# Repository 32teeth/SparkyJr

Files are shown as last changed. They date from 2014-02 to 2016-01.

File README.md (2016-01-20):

SparkyJr icon

-------------

# Introduction

**SparkyJr.** is a programmable RGB LED mod companion light up activation controller for arcade pushbuttons on gaming fightsticks.

The hardware is based on AVR microcontrollers and programmed via [AVR Studio](http://www.atmel.ca/microsite/atmel_studio6/) or the [Arduino IDE](http://arduino.cc/en/Main/Software)

**<span style="color:red">*note:*</span> please use Arduino IDE 1.0.6**

Open Source icon

**SparkyJr.** in it's entirety is open source. Including hardware design, software implementation and libraries
***
##Software
####Arduino icon Arduino

**SparkyJr.** Arduino based files are located in the *[arduino](https://github.com/32teeth/SparkyJr/tree/gh-pages/arduino/Sparky)* folder

This includes all the files required to upload to your specific AVR chipset.

**SparkyJr** only has one library dependency. We make use of the [EEPROMx](https://github.com/autohome/autohome-arduino/tree/master/libraries/EEPROMx) library

*for help on installing libraries into the Arduino IDE, please visit the [how to](http://arduino.cc/en/Guide/Libraries) on the Arduino site

####Processing icon Processing
**SparkyJr.** Processing based files are located in the *[processing](https://github.com/32teeth/SparkyJr/tree/gh-pages/processing)* folder

This includes all the files required to run the configurator.

####Google Chrome icon Google Chrome App
**SparkyJr.**'s configurator is additionally available as a Google Chrome Application and is available unpackaged in the [google](https://github.com/32teeth/SparkyJr/tree/gh-pages/google) folder

***
##Hardware
####Eagle Cad icon Eagle CAD
All of the PCB design, schema and board layout files where designed in [CadSoft's Eagle Cad PCB](http://www.cadsoftusa.com/eagle-pcb-design-software/product-overview/?language=en) software.

The .sch and .brd files are available in the [eagle](https://github.com/32teeth/SparkyJr/tree/gh-pages/eagle) folder.

####SparkyJr. hardware variants
*all versions are currenlty supported in the new SparkyJr software and configurator*

|  v1 | v2 (pwm)  | v3 (ftdi) (32u4)  | *v4* (current)  | v4 (expansion) |
|---|---|---|---|---|
|retired|retired|deprecated|current release|expansion board|
|  Arduino icon |  Arduino icon | Arduino icon  |  Arduino icon |  Arduino icon |
| | |  ftdi [sch](https://github.com/32teeth/SparkyJr/blob/gh-pages/eagle/SparkyJr_v4FTDI.sch) [brd](https://github.com/32teeth/SparkyJr/blob/gh-pages/eagle/SparkyJr_v4FTDI.brd) |  [sch](https://github.com/32teeth/SparkyJr/blob/gh-pages/eagle/SparkySpecialK.sch) [brd](https://github.com/32teeth/SparkyJr/blob/gh-pages/eagle/SparkySpecialK.brd) | [sch](https://github.com/32teeth/SparkyJr/blob/gh-pages/eagle/SparkySpecialKExpansion.sch) [brd](https://github.com/32teeth/SparkyJr/blob/gh-pages/eagle/SparkySpecialKExpansion.brd)  |
| | |  32u4 [sch](https://github.com/32teeth/SparkyJr/blob/gh-pages/eagle/SparkyJr_v432u4.sch) [brd](https://github.com/32teeth/SparkyJr/blob/gh-pages/eagle/SparkyJr_v432u4.brd) | | |

***
## Arduino
Arduino icon

Start up your Arduino IDE and open **Sparky.ino**
The only file you *need* to change settings in is the [setup.h](https://github.com/32teeth/SparkyJr/blob/gh-pages/arduino/Sparky/setup.h) file

to identify your board to the SparkyJr software, simply uncomment the right line
the comments in the code indicate the proper name

```
/*
** @define (DRIVER|LEO|UNO|JOY|RAZER)
** @desc DRIVER = Arduino WS2811 Shield
** @desc LEO = Arduino Leonardo
** @desc SPARKY = SparkyJrFTDI
** @desc UNO = Arduino UNO
** @desc JOY = Arduino Joystick Shield
** @desc RAZER = Razer Atrox Arcade Stick
*/
#define DRIVER
//#define LEO
//#define SPARKY
//#define UNO
//#define JOY
//#define RAZER
```
to identify your RGB LED type to the SparkyJr software, simply uncomment the right line

```
/*
** @define (ANODE|CATHODE)
** @desc ANODE = Common Anode RGB LEDs
** @desc CATHODE = Common Cathode RGB LEDs
*/
#define ANODE
//#define CATHODE
```
Complie and Run!

***
## Processing
Processing icon

if you are on a Mac, you're in luck. There is a packaged application available for you. Simply download the [SparkyOfficial.app](https://github.com/32teeth/SparkyJr/tree/gh-pages/processing/SparkyOfficial/SparkyOfficial/application.macosx/SparkyOfficial.app) file

if you are looking to run the application from source, simply download Processing and run the [SparkyOfficial.pde](https://github.com/32teeth/SparkyJr/blob/gh-pages/processing/SparkyOfficial/SparkyOfficial/SparkyOfficial.pde) file

***
Should you run into any trouble, or have further questions, feel free to reach out.

[Facebook icon 32teeth](https://www.facebook.com/32teeth)

[Twitter icon eugeneyevhen](https://twitter.com/eugeneyevhen)

[Github icon SparkyJr](32teeth.github.io/SparkyJr)

[LinkedIn icon 32teeth](http://ca.linkedin.com/in/32teeth)

***
# Thanks

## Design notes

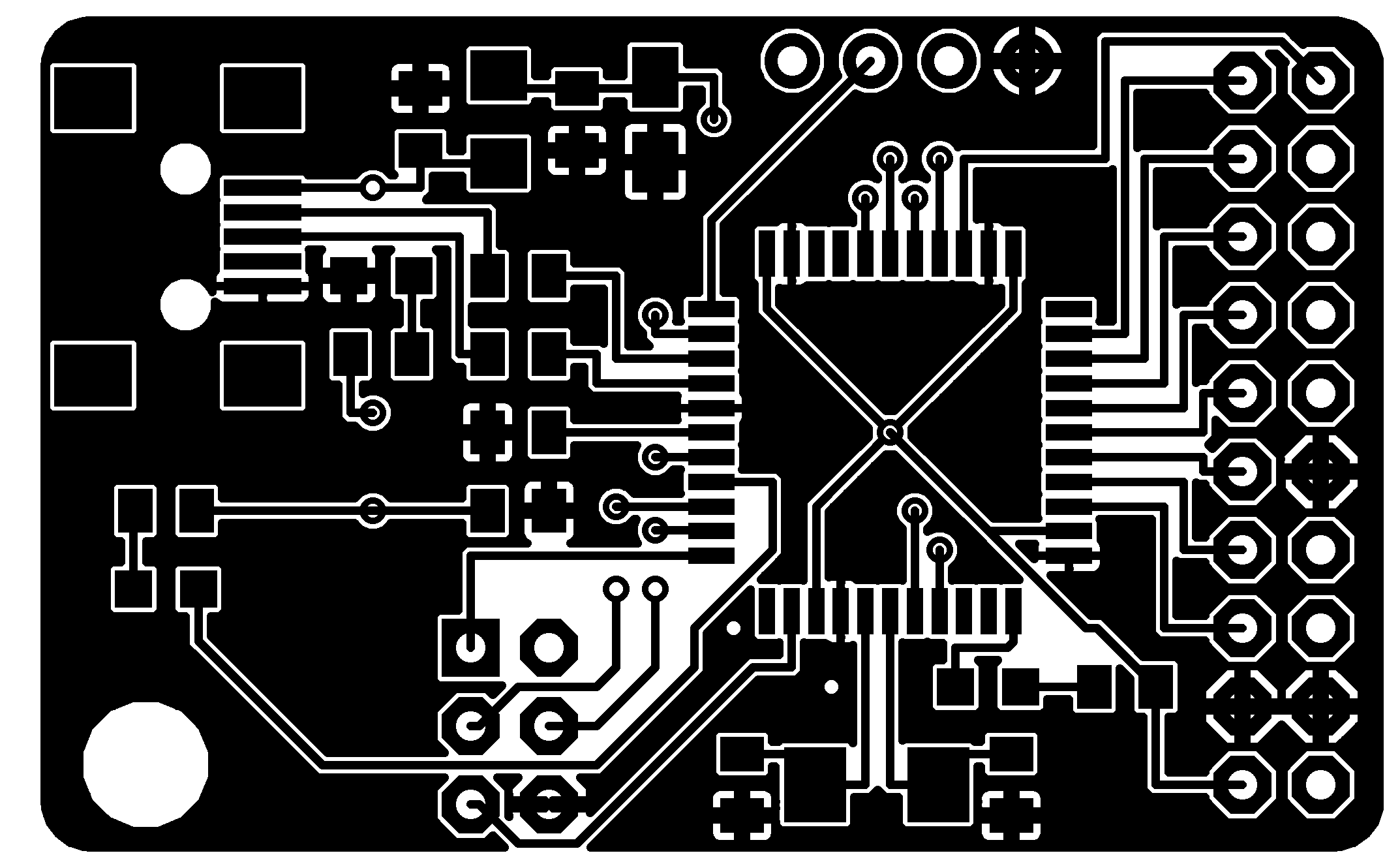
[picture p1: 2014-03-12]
eagle/eagleUp/eagleUp_SparkySpecialK_top.png

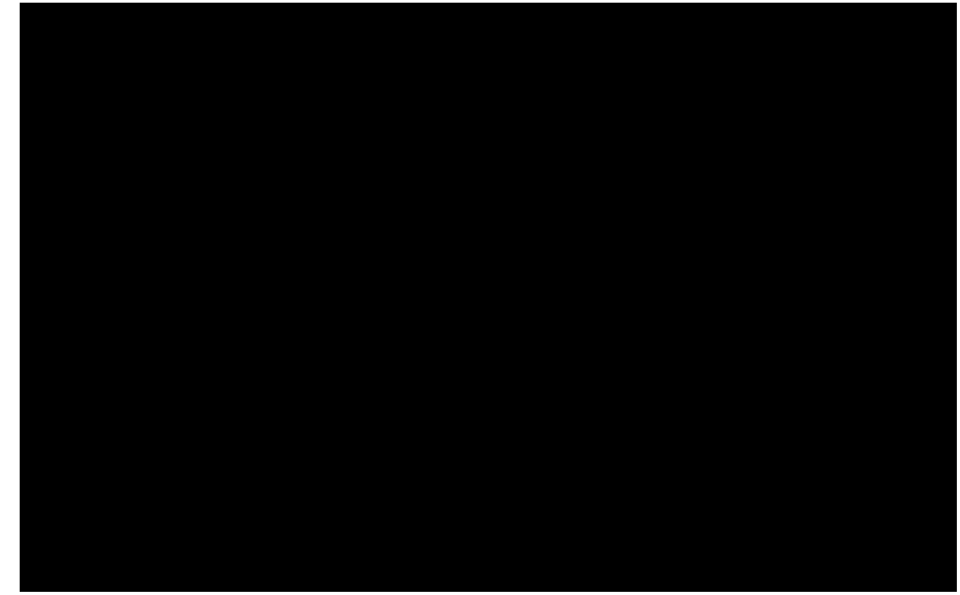
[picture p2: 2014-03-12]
eagle/eagleUp/eagleUp_SparkySpecialK_imagesize.png

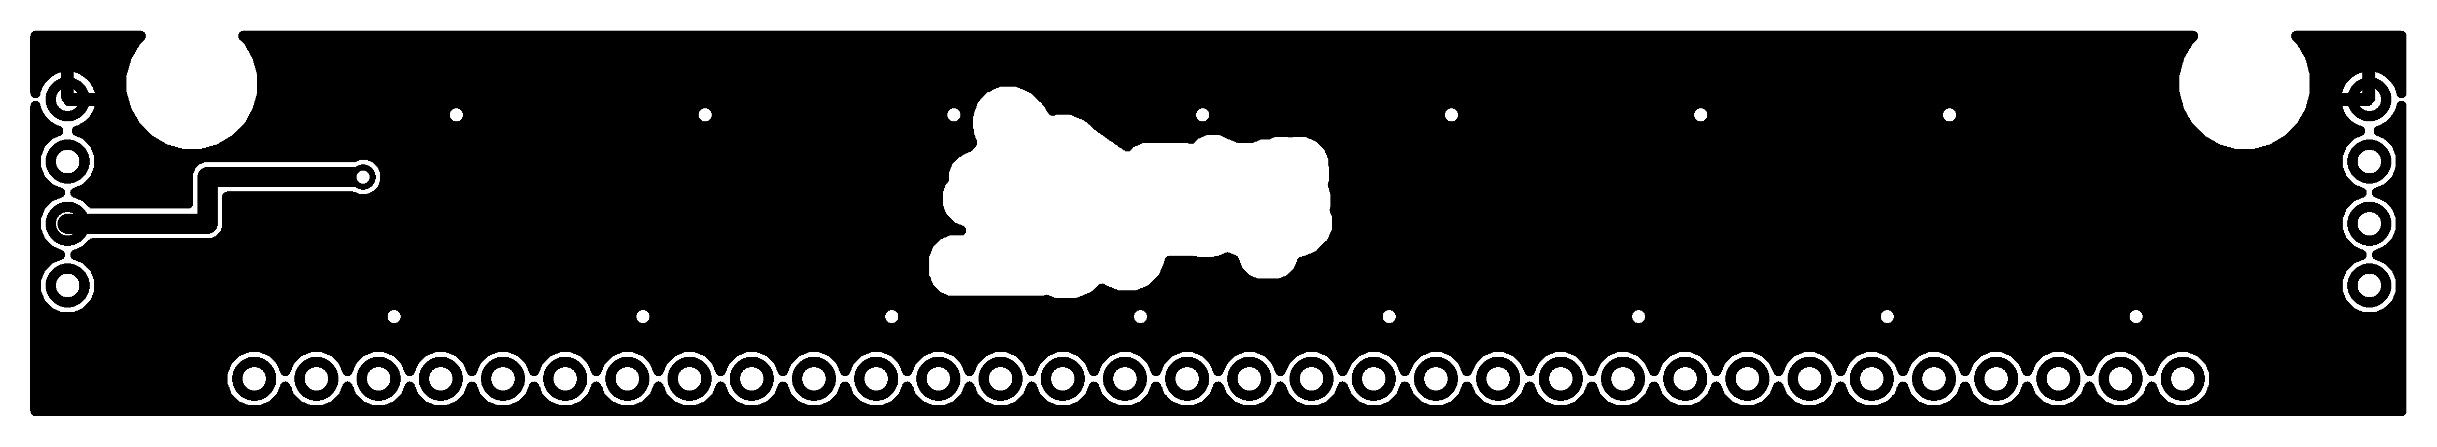
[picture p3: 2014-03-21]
eagle/eagleUp/eagleUp_SparkySpecialKExpansion_bottom.png

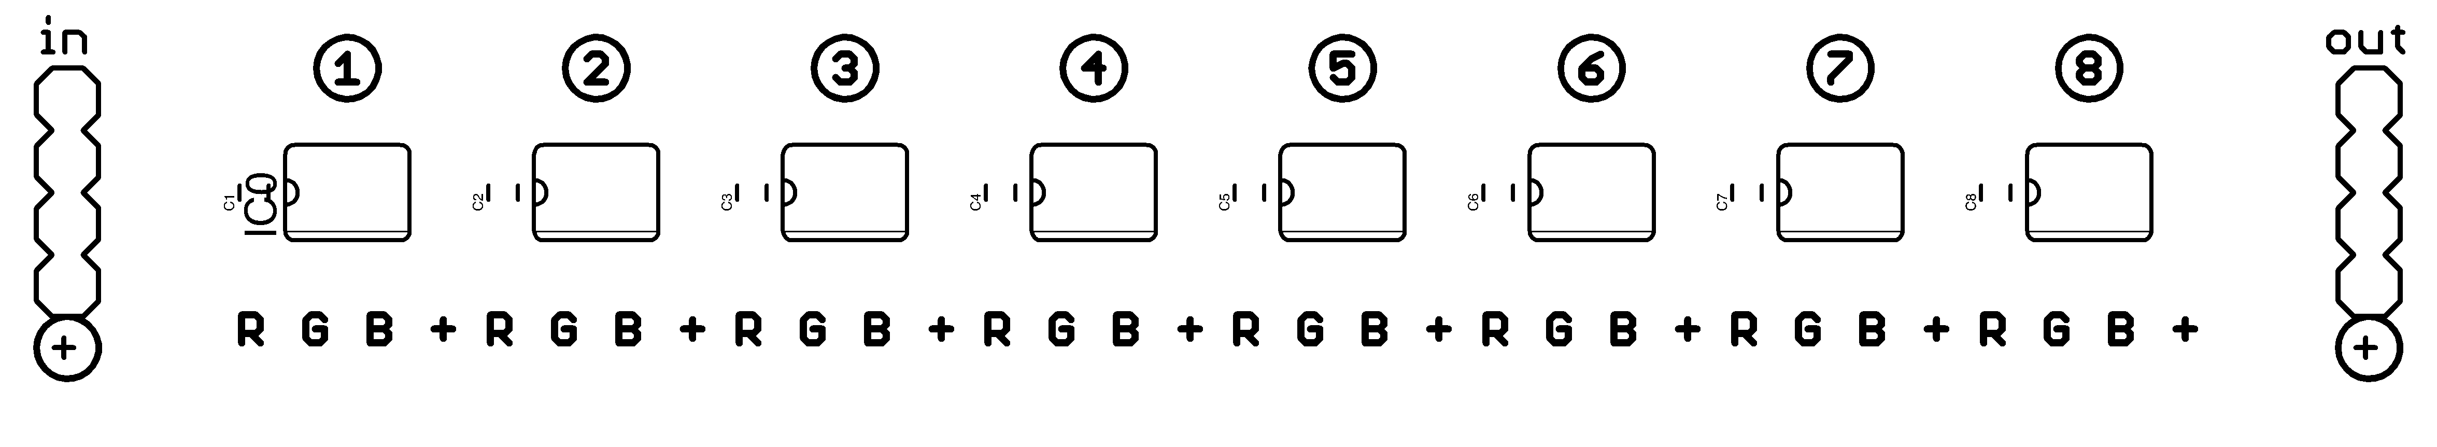
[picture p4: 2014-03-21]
eagle/eagleUp/eagleUp_SparkySpecialKExpansion_top_silk.png

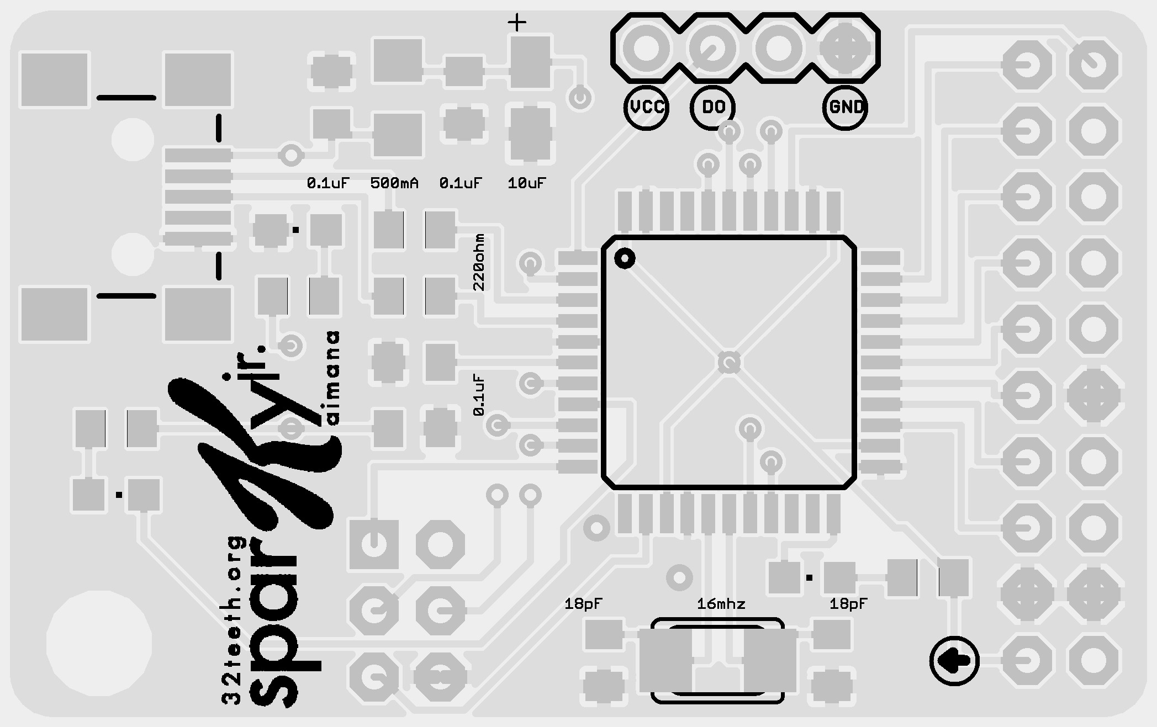
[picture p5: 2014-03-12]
eagle/eagleUp/eagleUp_SparkySpecialK_board_top.jpg

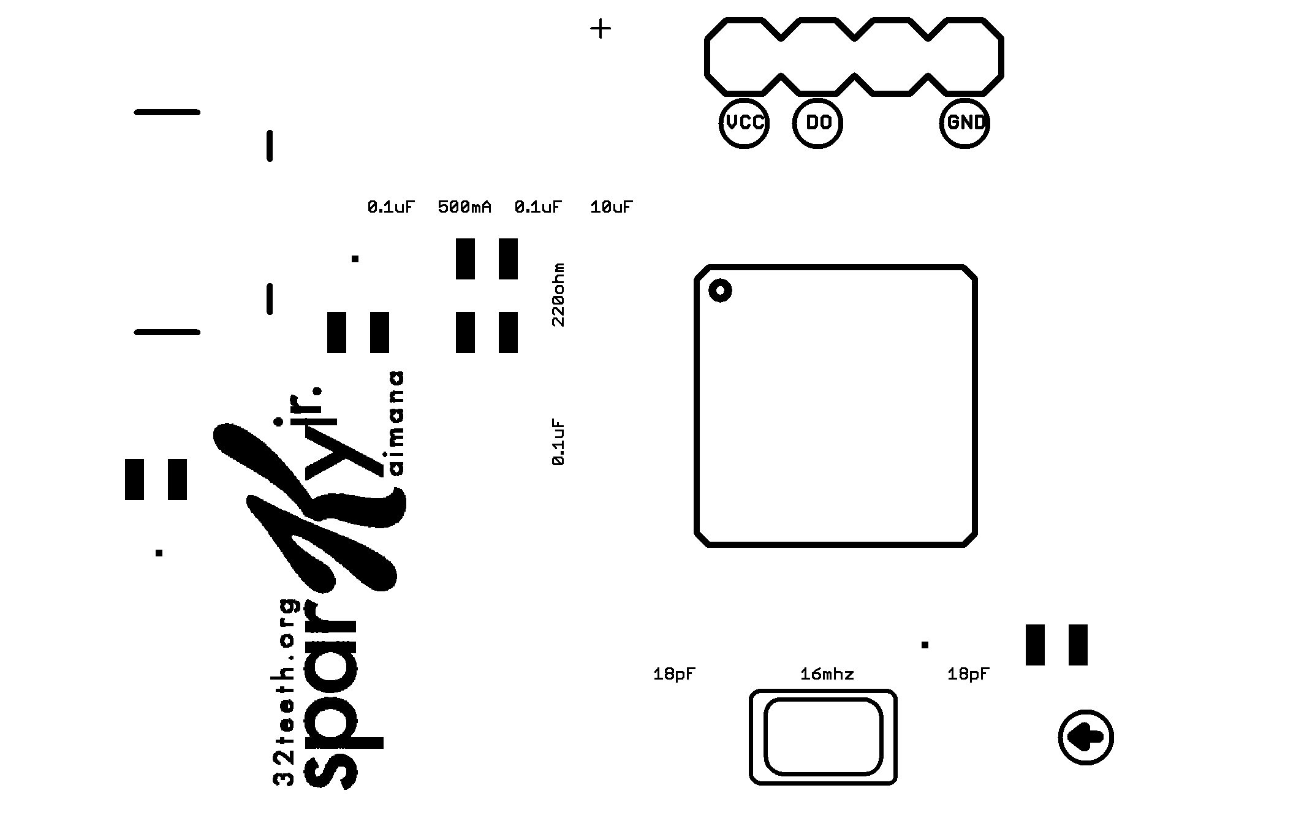
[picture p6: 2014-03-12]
eagle/eagleUp/eagleUp_SparkySpecialK_top_silk.png

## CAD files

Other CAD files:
eagle/sketchUp.skp

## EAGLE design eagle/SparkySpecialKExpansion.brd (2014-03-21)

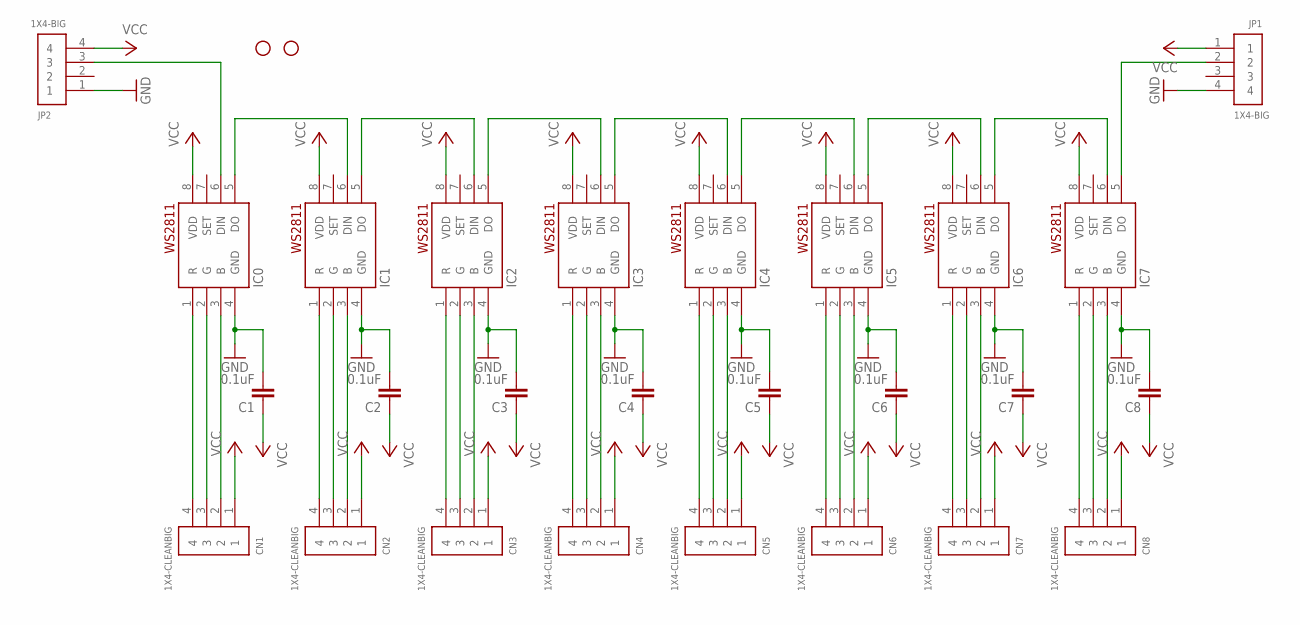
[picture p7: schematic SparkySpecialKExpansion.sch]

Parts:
C1, C2, C3, C4, C5, C6, C7, C8: 0.1uF; 0805
CN1, CN2, CN3, CN4, CN5, CN6, CN7, CN8: 1X4-CLEANBIG; 1X04-CLEANBIG
IC0, IC1, IC2, IC3, IC4, IC5, IC6, IC7: WS2811-SOP8; SO08-SKINNYPADS
JP1, JP2: 1X4-BIG; 1X04-BIG
JP3, JP4: STAND-OFF

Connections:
GND: C1.2, C2.2, C3.2, C4.2, C5.2, C6.2, C7.2, C8.2, IC0.4 (GND), IC1.4 (GND), IC2.4 (GND), IC3.4 (GND), IC4.4 (GND), IC5.4 (GND), IC6.4 (GND), IC7.4 (GND), JP1.4, JP2.1
unnamed: CN1.2, IC0.3 (B)
unnamed: CN1.3, IC0.2 (G)
unnamed: CN1.4, IC0.1 (R)
unnamed: CN2.4, IC1.1 (R)
unnamed: CN2.3, IC1.2 (G)
unnamed: CN2.2, IC1.3 (B)
unnamed: CN3.4, IC2.1 (R)
unnamed: CN3.3, IC2.2 (G)
unnamed: CN3.2, IC2.3 (B)
unnamed: CN4.4, IC3.1 (R)
unnamed: CN4.3, IC3.2 (G)
unnamed: CN4.2, IC3.3 (B)
unnamed: CN5.4, IC4.1 (R)
unnamed: CN5.3, IC4.2 (G)
unnamed: CN5.2, IC4.3 (B)
unnamed: CN6.4, IC5.1 (R)
unnamed: CN6.3, IC5.2 (G)
unnamed: CN6.2, IC5.3 (B)
unnamed: CN7.4, IC6.1 (R)
unnamed: CN7.3, IC6.2 (G)
unnamed: CN7.2, IC6.3 (B)
unnamed: CN8.4, IC7.1 (R)
unnamed: CN8.3, IC7.2 (G)
unnamed: CN8.2, IC7.3 (B)
unnamed: IC0.5 (DO), IC1.6 (DIN)
unnamed: IC1.5 (DO), IC2.6 (DIN)
unnamed: IC2.5 (DO), IC3.6 (DIN)
unnamed: IC3.5 (DO), IC4.6 (DIN)
unnamed: IC4.5 (DO), IC5.6 (DIN)
unnamed: IC5.5 (DO), IC6.6 (DIN)
unnamed: IC6.5 (DO), IC7.6 (DIN)
unnamed: IC7.5 (DO), JP1.2
unnamed: IC0.6 (DIN), JP2.3
VCC: C1.1, C2.1, C3.1, C4.1, C5.1, C6.1, C7.1, C8.1, CN1.1, CN2.1, CN3.1, CN4.1, CN5.1, CN6.1, CN7.1, CN8.1, IC0.8 (VDD), IC1.8 (VDD), IC2.8 (VDD), IC3.8 (VDD), IC4.8 (VDD), IC5.8 (VDD), IC6.8 (VDD), IC7.8 (VDD), JP1.1, JP2.4

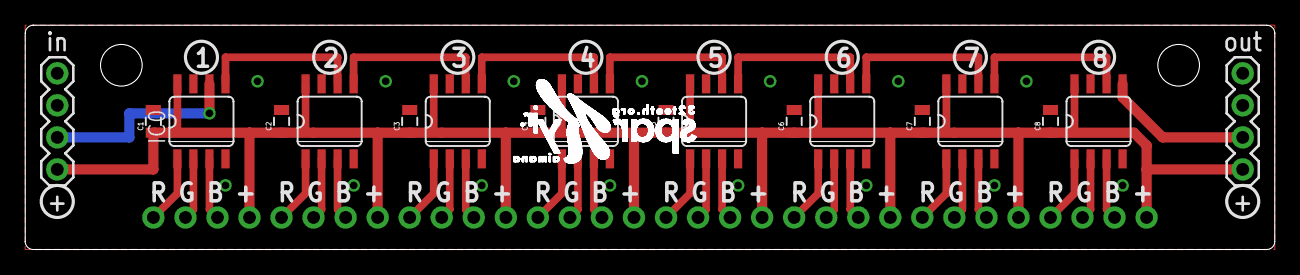
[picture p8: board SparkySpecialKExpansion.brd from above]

Board: 2 copper layers, 99.1 x 17.8 mm, 28 parts (0 on the bottom side), 35 nets.

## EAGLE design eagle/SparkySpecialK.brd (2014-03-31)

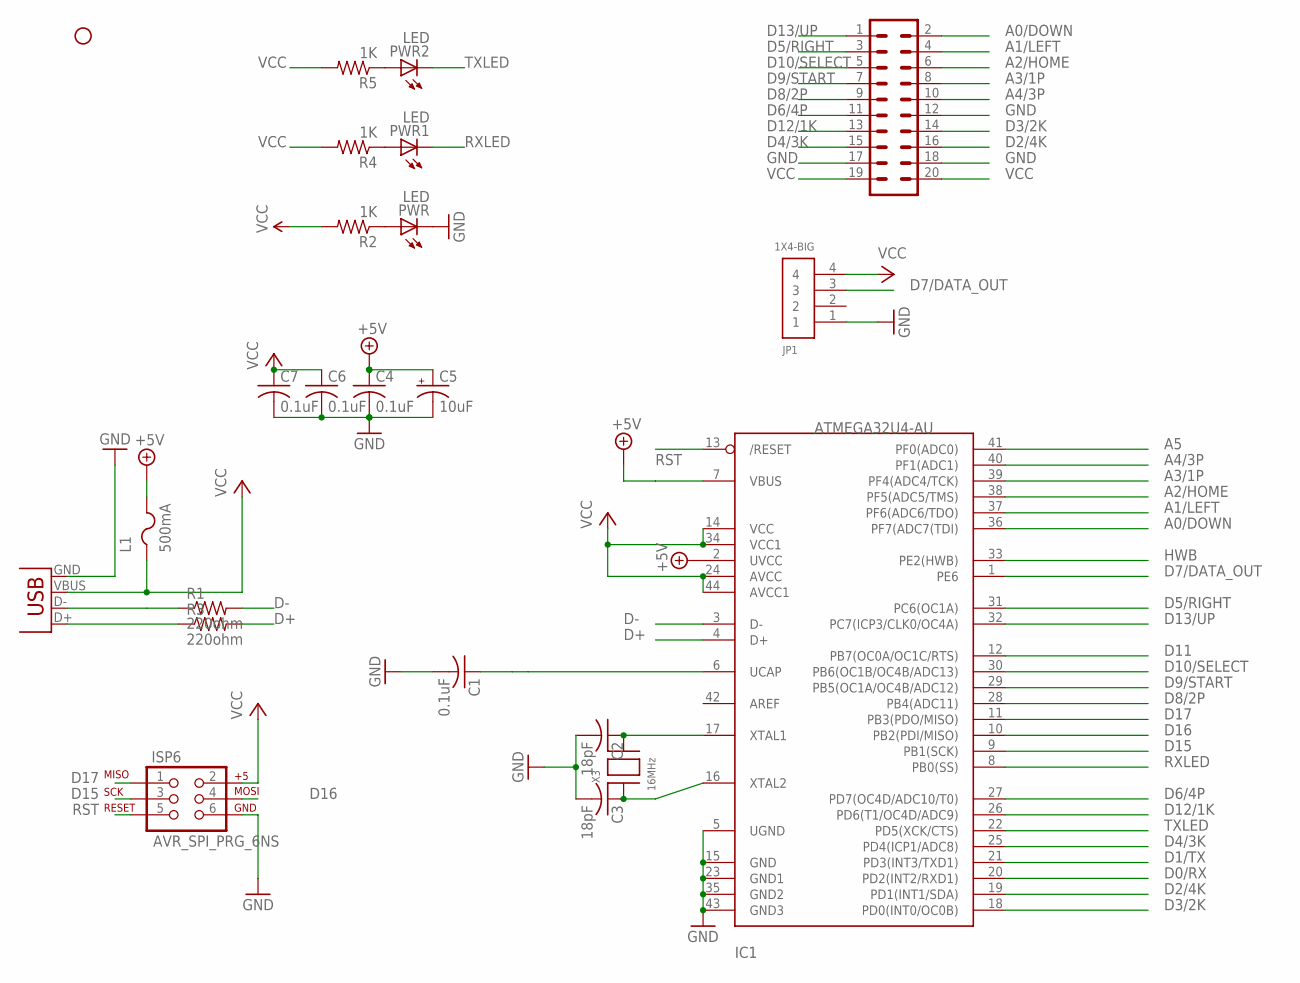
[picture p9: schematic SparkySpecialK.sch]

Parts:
C1, C4, C6, C7: 0.1uF; C0805K
C2, C3: 18pF; C0805K
C5: 10uF; A/3216-18R
CN1: MiniB USB; USB-MINIB
IC1: ATMEGA32U4-AU; TQFP44
ISP6: AVR_SPI_PRG_6NS; 2X3-NS
JP1: 1X4-BIG; 1X04-BIG
JP2: STAND-OFF
L1: 500mA; R1206
PWR, PWR1, PWR2: LED; CHIPLED_0805
R1, R3: 220ohm; R0805
R2, R4, R5: 1K; R0805
U$1: M10X2NOSILK; 2X10_NOSILK
X3: 16MHz; NX5032

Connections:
+5V: C4.1, C5.+, IC1.2 (UVCC), IC1.7 (VBUS), L1.2
A0/DOWN: IC1.36 (PF7(ADC7(TDI)), U$1.2
A1/LEFT: IC1.37 (PF6(ADC6/TDO)), U$1.4
A2/HOME: IC1.38 (PF5(ADC5/TMS)), U$1.6
A3/1P: IC1.39 (PF4(ADC4/TCK)), U$1.8
A4/3P: IC1.40 (PF1(ADC1)), U$1.10
A5: IC1.41 (PF0(ADC0))
D0/RX: IC1.20 (PD2(INT2/RXD1))
D1/TX: IC1.21 (PD3(INT3/TXD1))
D2/4K: IC1.19 (PD1(INT1/SDA)), U$1.16
D3/2K: IC1.18 (PD0(INT0/OC0B)), U$1.14
D4/3K: IC1.25 (PD4(ICP1/ADC8)), U$1.15
D5/RIGHT: IC1.31 (PC6(OC1A)), U$1.3
D6/4P: IC1.27 (PD7(OC4D/ADC10/T0)), U$1.11
D7/DATA_OUT: IC1.1 (PE6), JP1.3
D8/2P: IC1.28 (PB4(ADC11)), U$1.9
D9/START: IC1.29 (PB5(OC1A/OC4B/ADC12)), U$1.7
D10/SELECT: IC1.30 (PB6(OC1B/OC4B/ADC13)), U$1.5
D11: IC1.12 (PB7(OC0A/OC1C/RTS))
D12/1K: IC1.26 (PD6(T1/OC4D/ADC9)), U$1.13
D13/UP: IC1.32 (PC7(ICP3/CLK0/OC4A)), U$1.1
D15: IC1.9 (PB1(SCK)), ISP6.3
D16: IC1.10 (PB2(PDI/MISO)), ISP6.4
D17: IC1.11 (PB3(PDO/MISO)), ISP6.1
D+: IC1.4 (D+), R3.2
D-: IC1.3 (D-), R1.2
GND: C1.2, C2.2, C3.2, C4.2, C5.-, C6.2, C7.2, CN1.GND, IC1.5 (UGND), IC1.15 (GND), IC1.23 (GND1), IC1.35 (GND2), IC1.43 (GND3), ISP6.6, JP1.1, PWR.C, U$1.12, U$1.17, U$1.18
HWB: IC1.33 (PE2(HWB))
unnamed: PWR.A, R2.1
unnamed: CN1.D+, R3.1
unnamed: C1.1, IC1.6 (UCAP)
unnamed: CN1.D-, R1.1
unnamed: PWR1.A, R4.1
unnamed: PWR2.A, R5.1
unnamed: C2.1, IC1.17 (XTAL1), X3.P$2
unnamed: C3.1, IC1.16 (XTAL2), X3.P$1
RST: IC1.13 (/RESET), ISP6.5
RXLED: IC1.8 (PB0(SS)), PWR1.C
TXLED: IC1.22 (PD5(XCK/CTS)), PWR2.C
VCC: C6.1, C7.1, CN1.VBUS, IC1.14 (VCC), IC1.24 (AVCC), IC1.34 (VCC1), IC1.44 (AVCC1), ISP6.2, JP1.4, L1.1, R2.2, R4.2, R5.2, U$1.19, U$1.20

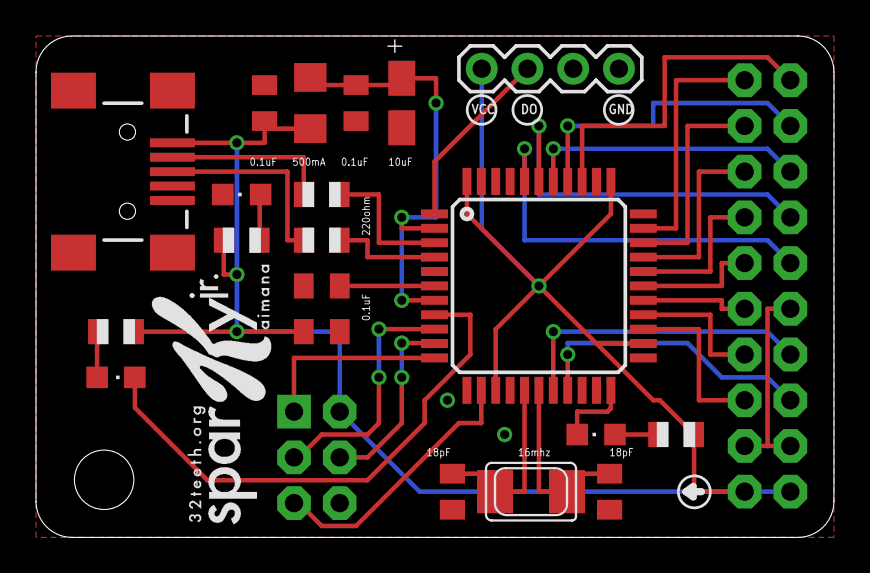
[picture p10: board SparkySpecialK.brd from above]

Board: 2 copper layers, 44.3 x 27.9 mm, 23 parts (0 on the bottom side), 35 nets.

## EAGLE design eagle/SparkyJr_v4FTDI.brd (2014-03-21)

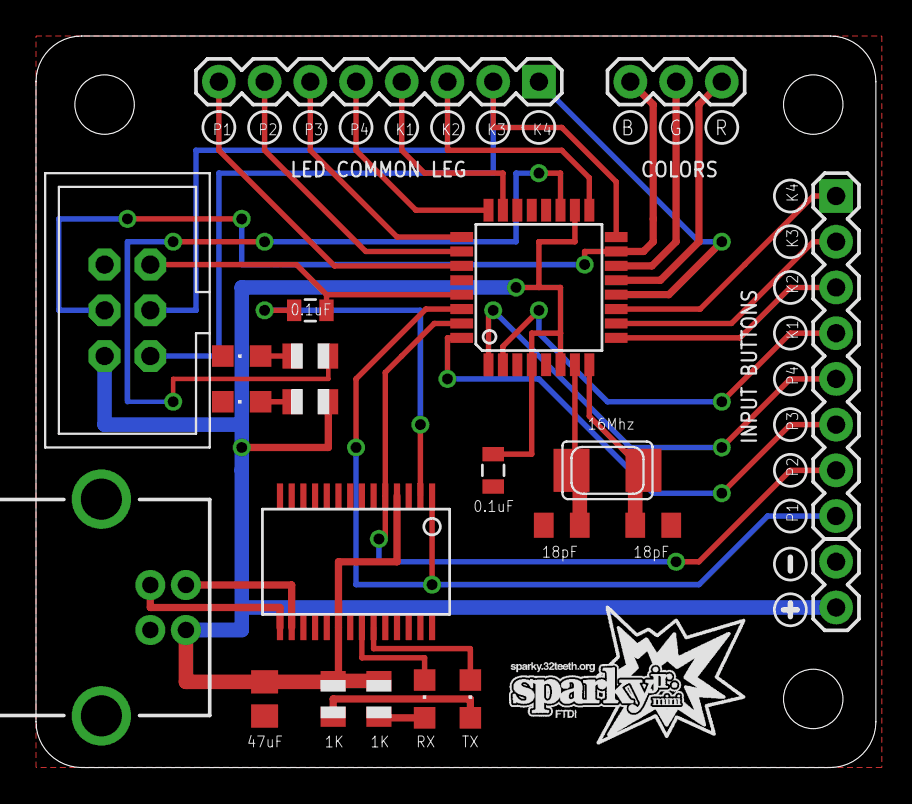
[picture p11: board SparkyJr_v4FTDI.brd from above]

Board: 2 copper layers, 46.7 x 40.6 mm, 25 parts (0 on the bottom side), 34 nets.

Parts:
C1, C2: 0.1uF; 0805
C3, C5: 18pF; C0805K
C4: 47uF; C0805
COMMON: 1X08
CONFIG: LED; CHIPLED_0805
IC2: FT232RLSSOP; SSOP28DB
IN: 1X02
INPUT: 1X08
ISP6: PINHD-2X3THM; ISP6
JP1, JP2, JP3: STAND-OFF
PWR: LED; CHIPLED_0805
R1, R3: 100Ohm; R0805
R2, R4: 1K; R0805
RGB2: 1X03
RXLED: Blue; CHIPLED_0805
TXLED: Blue; CHIPLED_0805
U1: ATMEGA328P; TQFP32-08
X1: USBPTH; USB-B-PTH
X3: 16MHz; NX5032

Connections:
BLUE: ISP6.4, RGB2.1, U1.15
C1: COMMON.8, U1.27
C2: COMMON.7, U1.26
C3: COMMON.6, U1.25
C4: COMMON.5, U1.24
C5: COMMON.4, U1.23
C6: COMMON.3, ISP6.3, U1.17
C7: COMMON.2, ISP6.1, U1.16
C8: COMMON.1, U1.12
CONFIG: R4.2, U1.19
D+: IC2.15, X1.D+
D-: IC2.16, X1.D-
DTR: C1.1, IC2.2
GND: C2.1, C3.2, C4.2, C5.2, CONFIG.C, IC2.7, IC2.11, IC2.18, IC2.21, IC2.25, IC2.26, IN.2, ISP6.6, PWR.C, U1.3, U1.5, U1.21, U1.28, X1.GND
GREEN: RGB2.2, U1.14
K1: INPUT.4, U1.2
K2: INPUT.3, U1.9
K3: INPUT.2, U1.10
K4: INPUT.1, U1.11
unnamed: PWR.A, R2.1
unnamed: CONFIG.A, R4.1
unnamed: R3.1, RXLED.A
unnamed: R1.1, TXLED.A
P3: INPUT.6, U1.32
P4: INPUT.5, U1.1
RED: RGB2.3, U1.13
RES1: C3.1, U1.7, X3.P$2
RES2: C5.1, U1.8, X3.P$1
RESET: C1.2, ISP6.5, U1.29
RX: IC2.22, RXLED.C
RX-P2: IC2.5, INPUT.7, U1.31
TX: IC2.23, TXLED.C
TX-P1: IC2.1, INPUT.8, U1.30
VCC: C2.2, C4.1, IC2.4, IC2.20, IN.1, ISP6.2, R1.2, R2.2, R3.2, U1.4, U1.6, U1.18, X1.VBUS

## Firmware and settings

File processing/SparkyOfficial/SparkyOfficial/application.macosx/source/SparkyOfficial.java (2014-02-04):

import processing.core.*; 
import processing.data.*; 
import processing.event.*; 
import processing.opengl.*; 

import java.util.*; 
import procontroll.*; 
import net.java.games.input.*; 
import java.io.*; 
import processing.serial.*; 

import java.util.HashMap; 
import java.util.ArrayList; 
import java.io.File; 
import java.io.BufferedReader; 
import java.io.PrintWriter; 
import java.io.InputStream; 
import java.io.OutputStream; 
import java.io.IOException; 

public class SparkyOfficial extends PApplet {

/*
** @author Eugene Andruszczenko
** @version 0.2
** @date January 30th, 2014
** @desc interface for Arduino based Sparky
*/

/*
** @desc all import files for controller
*/





ControllIO HIDs;
String HID = "";
String activeHID = "";

/*
** @desc all import files and definitions for serial and arduino
*/
 
Serial port;
String portstring = "";
String activeportstring = "";
int activeport;
String ports[];
int serial;
String command = "";
String action = "";
Boolean exec = false;
int baudrate = 115200;
boolean open = false;

/*
** @desc set mouse type
** 0 = ARROW, 1 = HAND, 2 = pin
*/
int mouseType = 0;

/*
** @desc fonts
*/
PFont fontOS10;
PFont fontOSL10;
PFont fontOS14;
PFont fontOSL14;
PFont fontOS18;
PFont fontOSL18;
PFont fontOS26;
PFont fontOSL26;
PFont fontSparky18;

/*
** @desc frame rate per second
*/
int fps = 120;

/*
** @desc width and height of full screen
*/
int dw, dh, dx, dy;

/*
** @desc 
*/

/*
** @desc madcatz buttons and colors
*/
boolean MADCATZ_LAYOUT = false;
int[] MADCATZ = {1,1,0,0,1,1,0,0};
int[][] MADCATZ_COLORS =  {{0,0,204}, {204,204,0}, {0,0,0}, {0,0,0}, {0,204,0}, {204,0,0}, {0,0,0}, {0,0,0}};

/*
** @desc hori buttons and colors
*/
boolean HORI_LAYOUT = false;
int[] HORI = {1,1,1,0,1,0,0,0};
int[][] HORI_COLORS =  {{204,0,0}, {0,0,204}, {204,204,0}, {0,0,0}, {0,204,0}, {0,0,0}, {0,0,0}, {0,0,0}};

/*
** @desc Intro Class
*/
Intro intro;
int duration = 30000;
float now = millis() + duration;

/*
** @desc Menu Class
*/
Menu menu;

/*
** @desc Stick class
*/
Stick stick;

/*
** @desc Connections class
*/
Connections connections;
boolean connection = false;

/*
** @desc Devices class
*/
Devices devices;
boolean device = false;

/*
** @desc Devices class
*/
Options options;
boolean option = false;

/*
** @desc Devices class
*/
Picker picker;
boolean selector = false;

/*
** @desc Devices class
*/
Com com;

/*
** @desc Devices class
*/
Quit quit;
boolean tryquit = false;

/*
** @desc width and height of full screen
*/
boolean activemodal = false;

/*
** @desc width and height of full screen
*/
boolean full = true;

/*
** @desc set to true to skip intro animation
*/
boolean loaded = false;

/*
** THIS
*/
SparkyOfficial SparkyOfficial = this;

/*
** @method setup
** @desc main processing setup
*/
public void setup()
{
  ports = Serial.list();
  
  smooth();
  /*
    @desc fonts
  */
  fontOS10 = createFont("OpenSans-Regular", 10, true);
  fontOSL10 = createFont("OpenSans-Light", 10, true);   
  fontOS14 = createFont("OpenSans-Regular", 14, true);
  fontOSL14 = createFont("OpenSans-Light", 14, true); 
  fontOS18 = createFont("OpenSans-Regular", 18, true);
  fontOSL18 = createFont("OpenSans-Light", 18, true);
  fontOS26 = createFont("OpenSans-Regular", 26, true);
  fontOSL26 = createFont("OpenSans-Light", 26, true);
  
  fontSparky18 = createFont("sparky", 18, true);
  
  textAlign(LEFT, TOP);
  
  
  frame.setTitle("Sparky Jr. Configurator");
  
  dw = full ? displayWidth : 800;
  dh = full ? displayHeight : 800; 
  dx = dw/2 - 640;
  dy = dh/2 - 512;
  
  
  size(dw, dh);

  frameRate(fps);
  background(255);
  
  noStroke();

  // set HID
  HIDs = ControllIO.getInstance(this);

  // intro
  intro = new Intro();
  intro.setup(); 
  
  // menu
  menu = new Menu();
  menu.setup();  
  
  // stick
  stick = new Stick();
  stick.setup();  
 
  // connection
  connections = new Connections();
  connections.setup();
  
  // device
  devices = new Devices();
  devices.setup();  
  
  // picker
  picker = new Picker();
  picker.setup();

  // picker
  options = new Options();
  options.setup(); 
 
  // com
  com = new Com(); 
  
  // quit
  quit = new Quit();
  quit.setup();   
}

/*
** @method draw
** @desc main processing loop
*/
public void draw()
{
  background(255);
  mouseType = 0;
  textAlign(LEFT, TOP);

  if(!activemodal && loaded)
  {
    stick.draw();
    menu.draw();
  }
  if(loaded)
  {
    if(!connection || !device)
    {
      activemodal = true;
      if(!connection)
      {
        connections.draw();
      }  
      if(connection && !device)
      {
        devices.draw();
      }
    }
    if(selector)
    {
      stick.draw();
      menu.draw();
      picker.draw();
    }    
    if(option)
    {
      stick.draw();
      menu.draw();
      options.draw();
    }    
    if(tryquit)
    {
      quit.draw();
    }
    
  }
  if(now > millis() && !loaded)
  {
    intro.draw();
  }  
  
  mouse();
}








/*
** @method sketchFullScreen
** @desc this is processing fullscreen mode based
*/
public boolean sketchFullScreen() {
  return full;
}

/*
*/
public void mouse()
{
  switch(mouseType)
  {
    case 0:
      cursor(ARROW);
    break;
    case 1:
      cursor(HAND);
    break;
    case 2:
      noCursor();
      //cursor(pencil, 0, 30);
    break;
  }    
}

public void mouseReleased() {
  if(exec && action != "")
  {
    if(action == "set")
    {
      com.set(stick.address, stick.COLOR);
    }
    exec = false;
    action = "";
    command = "";
  }
}

/*
** @author Eugene Andruszczenko
** @version 0.1
** @date January 3rd, 2014
** @desc interface for Arduino based SparkyFive
*/

class Com
{  
  /*
  ** @method setup
  ** @param command {String} (erase|print|reset|help)
  ** @desc used to call and recieve serial commands to arduino
  */  
  public void send(String command)
  {
    if(port.available() > 0)
    {
      port.write(command);
      recieve();
    }
  }

  /*
  ** @method set
  ** @desc set a specific EEPROM address block value
  ** @param address {int} clr {long}
  ** @example set 127 12345
  */  
  public void set(int address, long clr)
  {    
    if(open)
    {
      println("set " + address + " " + clr);
      port.write("set " + address + " " + clr);
      port.write("display " + address);
      delay(2500);
    }
  }

  /*
  ** @method get
  ** @desc get a specific EEPROM address block value
  ** @param address {int}
  ** @example get 127
  */  
  public void get(int address)
  {
    if(port.available() > 0)
    {
      port.write("get " + address);
      recieve();
    }
  }  

  /*
  ** @method press
  ** @desc press a specific EEPROM address block value
  ** @param address {int}
  ** @example press 127
  */  
  public void press(int address)
  {
    if(port.available() > 0)
    {
      port.write("set " + address);
      recieve();
    }
  }

  /*
  ** @method display
  ** @desc display a specific EEPROM address block value
  ** @param address {int}
  ** @example display 127
  */  
  public void display(int address)
  {
    if(port.available() > 0)
    {
      port.write("display " + address);
      recieve();
    }
  }    

  /*
  ** @method setup
  ** @param command {String} (erase|print|reset|help)
  ** @desc used to recieve serial commands to arduino
  */  
  public void recieve()
  {
    if(port.available() > 0)
    {
      println(port.read());     
    }
    
    while (port.available() > 0) {
      String inBuffer = port.readString();   
      if (inBuffer != null) {
        println(inBuffer);
      }
    }     
  }  
}
/*
** @author Eugene Andruszczenko
** @version 0.1
** @date January 30th, 2014
** @desc interface for Arduino based SparkyFive
*/

/*
** @class Connections
** @desc draw modal and list connections for selectsion
*/
class Connections
{  
  int page = 0;
  PImage[] pages = new PImage[5];
  PImage blur = loadImage("blur.png");
  PImage state;
  
  int[] button = {(dw/2)-(740/2),512,(dw/2)+(740/2),612};
  int[] close = {(dw/2)+310,155,(dw/2)+370,215};
  int fx = (dw/2)-(740/2)+20;
  int fy = 285;
  
  int inc = 0;
  /*
  ** @method setup
  ** @desc set initial state
  */  
  public void setup()
  {
    pages[0] = loadImage("serial.png");
    pages[1] = loadImage("serial-hover.png");
    pages[2] = loadImage("serial-connection.png");
    pages[3] = loadImage("serial-connection-hover.png");
    pages[4] = loadImage("serial-connection-inactive.png");
    
    state = pages[0];
  }
  
  public void draw()
  {
    tint(255, 255);
    image(blur, dx, 0);
    if(inc < 255)
    {
      tint(255, inc);
      inc+=15;
    }    
    image(state, dx, 0);
    state = page == 0 ? pages[0] : pages[4];
    if(page == 1)
    {
      connections();
    }  
    mouse();
  }
  
  public void connections()
  {
    fill(102);
    for(int n = 0; n < ports.length; n++)
    {
      fill(204);
      if(ports[n].equals(portstring)){fill(102);}else{fill(204);}
      if(ports[n].equals(activeportstring)){fill(0,153,153);}

      textFont(fontSparky18);
      text("f", fx, fy + (n*30) + 5);
      
      textFont(fontOSL18);
      text(ports[n], fx + 25, fy + (n*30));    
    }    
  }
  
  /*
  ** @method mouse
  ** @desc read x and y coordinates of the mouse and set hover states
  */     
  public void mouse()
  {
    int mx = mouseX;
    int my = mouseY;
    
    /*
      close
    */
    if(mx > close[0] && mx < close[2] && my > close[1] && my < close[3])
    {
      mouseType = 1;
      if(mousePressed)
      {
        page = 0;
        activemodal = false;
        connection = true;
        tint(255, 255);
      }
    }
    
    /*
      button
    */
    if(mx > button[0] && mx < button[2] && my > button[1] && my < button[3])
    {
      mouseType = 1;
      if(page == 0)
      {
        state = pages[1];
        if(mousePressed)
        {
          page = 1;
        }
      }
      if(page == 1)
      {
        state = activeportstring == "" ? pages[4] : pages[3];
        if(mousePressed && activeportstring != "")
        {
          connection = true;
          port = new Serial(SparkyOfficial, Serial.list()[activeport], baudrate);
          activemodal = false;
          open = true;
          inc = 0;
        }        
      }      
    }
    else
    {
      if(page == 0)
      {
        state = pages[0];
      }
      if(page == 1)
      {
        state = activeportstring == "" ? pages[4] : pages[2];
      }       
    }
    
    /*
      list
    */
    if(page == 1)
    {
      int lx[] = {fx, (fx + 700)};
      int ly[] = {fy, (fy + (ports.length * 30))};

      portstring = "";
      if(mx > lx[0] && mx < lx[1] && my > ly[0] && my < ly[1])
      {
        mouseType = 1;
        int p = ((my-ly[0])/30);
        if(p < ports.length)
        {
          if(portstring != Serial.list()[p])
          {
            portstring = Serial.list()[p];
            if(mousePressed)
            {
               activeport = p;
               activeportstring = portstring;
            }            
          }   
        }        
      }      
    }
    
  }
}
/*
** @author Eugene Andruszczenko
** @version 0.1
** @date January 30th, 2014
** @desc interface for Arduino based SparkyFive
*/

/*
** @class Devices
** @desc draw modal and list connections for selectsion
*/
class Devices
{  
  int page = 0;
  PImage[] pages = new PImage[5];
  PImage blur = loadImage("blur.png");
  PImage state;
  
  int[] button = {(dw/2)-(740/2),512,(dw/2)+(740/2),612};
  int[] close = {(dw/2)+310,155,(dw/2)+370,215};
  int fx = (dw/2)-(740/2)+20;
  int fy = 285;
  
  int inc = 0;
  /*
  ** @method setup
  ** @desc set initial state
  */  
  public void setup()
  {
    pages[0] = loadImage("device.png");
    pages[1] = loadImage("device-hover.png");
    pages[2] = loadImage("device-connection.png");
    pages[3] = loadImage("device-connection-hover.png");
    pages[4] = loadImage("device-connection-inactive.png");
    
    state = pages[0];
  }
  
  public void draw()
  {
    tint(255, 255);
    image(blur, dx, 0);
    if(inc < 255)
    {
      tint(255, inc);
      inc+=15;
    }   
    image(state, dx, 0);
    state = page == 0 ? pages[0] : pages[4];
    if(page == 1)
    {
      devices();
    }  
    mouse();
  }
  
  public void devices()
  {
    fill(102);
    for(int n = 2; n < HIDs.getNumberOfDevices(); n++)
    {
      fill(204);
      if(HIDs.getDevice(n).getName().equals(HID)){fill(102);}else{fill(204);}
      if(HIDs.getDevice(n).getName().equals(activeHID)){fill(0,153,153);}

      textFont(fontSparky18);
      text("f", fx, fy + ((n-2)*30) + 5);
      
      textFont(fontOSL18);
      text(HIDs.getDevice(n).getName(), fx + 25, fy + ((n-2)*30));    
    }    
  }
  
  /*
  ** @method mouse
  ** @desc read x and y coordinates of the mouse and set hover states
  */     
  public void mouse()
  {
    int mx = mouseX;
    int my = mouseY;
    
    /*
      close
    */
    if(mx > close[0] && mx < close[2] && my > close[1] && my < close[3])
    {
      mouseType = 1;
      if(mousePressed)
      {
        page = 0;
        activemodal = false;
        device = true;
        tint(255, 255);
      }
    } 
    
    /*
      button
    */
    if(mx > button[0] && mx < button[2] && my > button[1] && my < button[3])
    {
      mouseType = 1;
      if(page == 0)
      {
        state = pages[1];
        if(mousePressed)
        {
          page = 1;
        }
      }
      if(page == 1)
      {
        state = activeHID == "" ? pages[4] : pages[3];
        if(mousePressed && activeHID != "")
        {
          device = true;
          activemodal = false;
          inc = 0;
        }          
      }      
    }
    else
    {
      if(page == 0)
      {
        state = pages[0];
      }
      if(page == 1)
      {
        state = activeHID == "" ? pages[4] : pages[2];        
      }       
    }
    
    /*
      list
    */
    if(page == 1)
    {
      int lx[] = {fx, (fx + 700)};
      int ly[] = {fy, (fy + (ports.length * 30))};

      HID = "";
      if(mx > lx[0] && mx < lx[1] && my > ly[0] && my < ly[1])
      {
        mouseType = 1;
        int p = ((my-ly[0])/30)+2;
        if(p < HIDs.getNumberOfDevices())
        {
          if(HID != HIDs.getDevice(p).getName())
          {
            HID = HIDs.getDevice(p).getName();
            if(mousePressed)
            {
              activeHID = HID;
            }            
          }   
        }        
      }      
    }
  }
}
/*
** @author Eugene Andruszczenko
** @version 0.2
** @date January 30th, 2014
** @desc interface for Arduino based Sparky
*/

/*
** @class Intro
** @desc draw intro screen
*/
class Intro
{
  /*
  ** @desc images required for this clip
  */
  PImage imgText = loadImage("intro-title.png");
  PImage imgRainbow = loadImage("intro-rainbow.png");
  PImage imgStick = loadImage("intro-stick.png");
  PImage imgBase = loadImage("base.png");
  PShape buttons = loadShape("buttons.svg");
  PImage menu = loadImage("menu.png");
  PImage base;
  
  int percent;
  int[] inc = {0,0,0,0,0,0,0};
  
  /*
  ** @method setup
  ** @desc set initial centering based on screen size and invoke draw()
  */
  public void setup()
  {
    base = createImage(1280, 100, ARGB);
    base.copy(menu, 0, 0, 1280, 100, 0, 0, 1280, 100);
  }
  
  /*
  ** @method draw
  ** @desc stub
  */
  public void draw()
  {
    float time = millis();
    if(time < 4000)
    {
      splash();
    }
    if(time > 4000 && time < 10000)
    {
      logo();
    }
    if(time > 10000 && time < 12000)
    {
      out();
    }
    if(time > 12000)
    {
      back();
    }
    if(time > 15000)
    {
      loaded = true;
    }
  }

  /*
  ** @method splash
  ** @desc draw splash text
  */
  public void splash()
  {
    int p = inc[0] < 255 ? 255-inc[0] : inc[0]-255;
    
    fill(p);
    textAlign(CENTER, CENTER);
    textFont(fontOSL14);
    text("32teeth", dw/2, dh/2);

    fill(127, 255-p);
    textFont(fontOSL10);
    text("presents", dw/2, dh/2+28);
    
    inc[0]+=2;
  }

  /*
  ** @method logo
  ** @desc fade logo and rainbow
  */
  public void logo()
  {
    int p = inc[1];
    if(p < 255){tint(255,p);}
    image(imgText, dx, dy);
    
    if(inc[1] > 255)
    {
      if(inc[2] < dh/2-50)
      {
        image(imgRainbow, dx, dh-inc[2]);
        inc[2]+=2;
      }
      else
      {
        tint(255,255-inc[3]);
        image(imgRainbow, dx, dh/2+50);
        tint(255,255);
        image(imgStick, dx, dh/2+50);
        inc[3]+=2;
      }
    }
    
    inc[1]+=2;
  } 
  
  /*
  ** @method out
  ** @desc fade out logo
  */  
  public void out()
  {
    int p = inc[4];
    if(p < 255){tint(255,255-p);}
    else{tint(255,0);}
    image(imgText, dx, dy);
    image(imgStick, dx, dh/2+50);
    inc[4]+=5;    
  }
  
  /*
  ** @method back
  ** @desc fade in background and drop in menu
  */   
  public void back()
  {
    int p = inc[5];
    if(p < 255){tint(255,p);}
    image(imgBase, dx, 0);
    shape(buttons, dx, 0);
    inc[5]+=5;
   
    if(inc[5] > 255 && inc[6] < 100)
    {
      image(base, dx, -100+inc[6]);
      inc[6]+=2;
    } 
    if(inc[6] == 100)
    {
      image(base, dx, 0);
    }
  }
}
/*
** @author Eugene Andruszczenko
** @version 0.2
** @date January 30th, 2014
** @desc interface for Arduino based Sparky
*/

/*
** @class Manu
** @desc draw menu and manage states
*/
class Menu
{
  /*
  ** @desc list of menu items and their string names
  */
  String items[] = {
    "serials",
    "devices",
    "colors",
    "options",
    "exit"
  };
  
  int mw = 120;
  int mh = 100;
  int offset = 440;
  
  int[][] mapX = {{0,0},{0,0},{0,0},{0,0},{0,0},{0,0},{0,0},{0,0}};
  
  PImage menu = loadImage("menu.png");
  PImage base;
  PImage[] off = new PImage[5];
  PImage[] hover = new PImage[5];
  PImage[] on = new PImage[5];
  PImage[] disabled = new PImage[5];
  int state;  
  
  /*
  ** @method setup
  ** @desc set initial centering based on screen size and invoke draw()
  **              create image sprites for active states (icon)
  **              create image sprites from menu image (menu)
  **              populate mapX array with approrpiate values for vertical location of sprites
  */  
  public void setup()
  {
    int x = offset;
    for(int i = 0; i < 5; i++)
    {
      mapX[i][0] = (x-offset)+(dw/2)-200;
      /*
      ** off states
      */
      off[i] = createImage(mw, mh, ARGB);
      off[i].copy(menu, x, 0, mw, mh, 0, 0, mw, mh);
      /*
      ** hover states
      */      
      hover[i] = createImage(mw, mh, ARGB);
      hover[i].copy(menu, x, mh, mw, mh, 0, 0, mw, mh);
      /*
      ** on states
      */
      on[i] = createImage(mw, mh, ARGB);
      on[i].copy(menu, x, mh*2, mw, mh, 0, 0, mw, mh);
      /*
      ** disabled states
      */      
      disabled[i] = createImage(mw, mh, ARGB);
      disabled[i].copy(menu, x, mh*3, mw, mh, 0, 0, mw, mh);
      
      x += mw;
      mapX[i][1] = (x-offset)+(dw/2)-200;
    }
    
    base = createImage(1280, mh, ARGB);
    base.copy(menu, 0, 0, 1280, mh, 0, 0, 1280, mh);
  }
  
  /*
  ** @method draw
  ** @desc set device states icons based on set parameters for icon display
  **              call mouse()
  */
  public void draw()
  {  
    // base
    image(base, dx, 0);
    mouse();
  }
  
  public void drop()
  {
    for(int n = 0; n < 100; n++)
    {
      image(base, dx, -100-n);
    }
  }

  /*
  ** @method mouse
  ** @desc read x and y coordinates of the mouse and set static, hover and clicked states
  */     
  public void mouse()
  {
    int mx = mouseX;
    int my = mouseY;
    PImage item; 
   
    for(int i = 0; i < 5; i++)
    {
      item = off[i];
      if(my > 0 && my < 100)
      {
        if(mx > mapX[i][0] && mx < mapX[i][1])
        {
          if(!activemodal)
          {
            item = hover[i];
            mouseType = 1;
            if(mousePressed)
            {
              //mouseType = 0;
              state = i;
              item = on[i];
              //delay(500);
              switch(state)
              {
                // connection
                case 0:
                  activemodal = true;
                  connection = false;
                  connections.inc = 0;
                  connections.page = 1;
                  if(open)
                  {
                    port.clear();
                    port.stop();
                  }
                break;
                // device
                case 1:
                  activemodal = true;
                  device = false;
                  devices.inc = 0;
                  devices.page = 1;
                break;
                case 2:
                  activemodal = true;
                  selector = true;    
                  MADCATZ_LAYOUT = false;
                  HORI_LAYOUT = false;            
                break;
                case 3:
                  activemodal = true;
                  option = true;
                break;
                case 4:
                  activemodal = true;
                  tryquit = true;
                break;
                default:
                break;
              }
            }
          }
        }
      }
      image(item, mapX[i][0], 0);
    } 
  }
}
/*
** @author Eugene Andruszczenko
** @version 0.1
** @date January 30th, 2014
** @desc interface for Arduino based SparkyFive
*/
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
  static public void main(String[] passedArgs) {
    String[] appletArgs = new String[] { "--full-screen", "--bgcolor=#666666", "--hide-stop", "SparkyOfficial" };
    if (passedArgs != null) {
      PApplet.main(concat(appletArgs, passedArgs));
    } else {
      PApplet.main(appletArgs);
    }
  }
}

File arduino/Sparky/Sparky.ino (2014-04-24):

/*
** @author Eugene Andruszczenko
** @version 0.1
** @date December 3rd, 2013
** @desc SparkyFive 
*/

/*
** @desc include setup
** @desc change your settings in this file
*/
#include "setup.h"

#ifdef NEO
  #include <Adafruit_NeoPixel.h>
  #ifndef JOY
    int pixels = 8;
  #endif  
  #ifdef JOY
    int pixels = 24;
  #endif    
  Adafruit_NeoPixel neo = Adafruit_NeoPixel(pixels, data, NEO_RGB + NEO_KHZ800);
#endif

/*
** @desc include utility
*/
#include "utility.h"

/*
** @desc include colors
*/
#include "colors.h"

/*
** @desc include eeprom files
*/
#include <EEPROMex.h>
#include "eeprom.h";

#include "io.h"

/*
** @desc layouts
*/
#include "layout.h"

/*
** @desc include programming and help files
*/
#include "help.h";
#include "programming.h";

#ifdef JOY
  #include "joystick.h"
#endif

/*
** @method setup
** @desc main arduino setup
*/
void setup()
{
  /*
  ** @desc start
  */  
  #ifdef NEO
    neo.begin();
    neo.setBrightness(255);
    neo.show();
  #endif
  
  /*
  ** @desc Timer adjustments
  */  
  TCCR1B = TCCR1B & 0b11111000 | 0x01; 
  #if !defined(LEO) && !defined(SPECIALK)
    TCCR2B = TCCR2B & 0b11111000 | 0x01;
  #endif

  /*
  ** @desc EEPROM Allocations 
  */
  #if !defined(LEO) && !defined(SPECIALK)
    EEPROM.setMemPool(1024 , EEPROMSizeUno);  
  #else
    EEPROM.setMemPool(1024 , EEPROMSizeATmega32u4);
  #endif 
  EEPROM.setMaxAllowedWrites(1024);
  addressLong = EEPROM.getAddress(sizeof(long));
  
  delay(1000);
  if(getLongEEPROM(0) == empty){randomEEPROM();}
  
  /*
  ** @desc set io functionality
  */  
  setIO();
  
  #ifdef JOY
    setJoystickIO();
  #endif   
  
  /*
  ** @desc run intro
  */
  //#define INTRO
  #ifdef INTRO
    introIO();
  #endif

  ///*
  displayIO(240, 16711680);
  displayIO(112, 16322304);
  displayIO(48, 16417024);
  displayIO(16, 4849408);

  if(digitalRead(pgm_read_byte(&inputs[4])) == 0)
  {
    displayIO(255, 16777215);
    configurator = true;
  }
  
  if(digitalRead(pgm_read_byte(&inputs[5])) == 0)
  {
    displayIO(255, 16777215);    
    MADCATZ_LAYOUT = true;
  }
 
  if(digitalRead(pgm_read_byte(&inputs[6])) == 0)
  {
    displayIO(255, 16777215);    
    HORI_LAYOUT = true;
  }  

  if(digitalRead(pgm_read_byte(&inputs[7])) == 0)
  {
    displayIO(255, 16777215);    
    OFFMODE = true;
  }    
  
  delay(1000);
  for(int n = 0; n < count; n++)
  {
    #ifndef NEO      
      digitalWrite(pgm_read_byte(&outputs[n]), LOW);
    #else
      neo.setPixelColor(n, 0, 0, 0);
    #endif        
  }    
  #ifdef NEO
    displayIO(255, 0); 
    neo.show();
  #endif  
  //*/

  //configurator = true;
  //MADCATZ_LAYOUT = true;
  //HORI_LAYOUT = true;

}

/*
** @method loop
** @desc main arduino loop
*/
void loop()
{
  if(!OFFMODE)
  {
    if(configurator){programming();}
    else
    {
      if(!MADCATZ_LAYOUT && !HORI_LAYOUT)
      {
        watchIO();
        now = millis();
      }
      else
      {
        if(MADCATZ_LAYOUT){madcatz();}
        if(HORI_LAYOUT){hori();}
      }
      
      #ifdef JOY
        dislpayJoystickIO();
      #endif  
    }
  }
}

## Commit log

2014-02-04 Added WS2811 Driver functionality
2014-03-12 added eagle and sketch up
    [SparkySpecialK.brd, SparkySpecialK.sch, sketchUp.skp]
2014-03-27 added stuff
    [SparkySpecialK.brd, SparkySpecialK.csv]
2014-03-31 updated connections
    [SparkySpecialK.brd, SparkySpecialK.csv, SparkySpecialK.sch]
2014-03-31 pin change for special

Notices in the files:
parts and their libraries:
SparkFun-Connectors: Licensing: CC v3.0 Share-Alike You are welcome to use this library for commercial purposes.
